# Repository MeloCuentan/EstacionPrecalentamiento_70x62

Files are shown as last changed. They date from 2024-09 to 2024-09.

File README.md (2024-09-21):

# Estacion de Precalentamiento

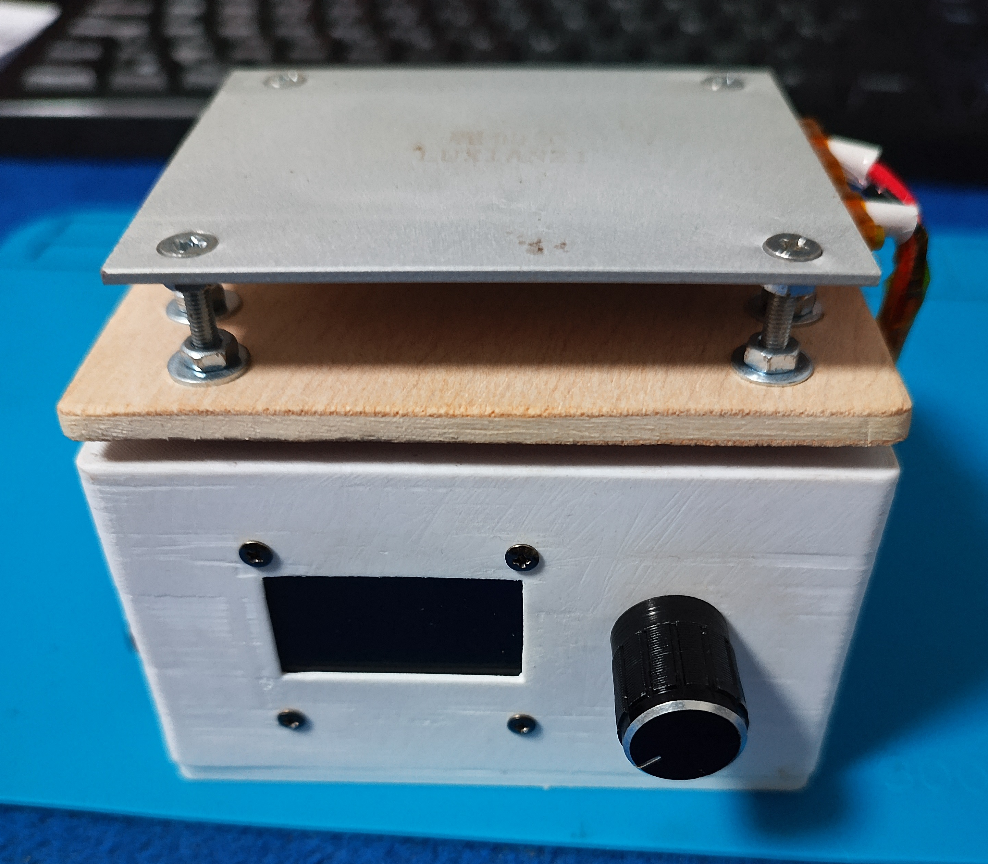
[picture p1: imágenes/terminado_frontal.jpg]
Foto Frontal


Esta es una estación de precalemtamiento para soldar componentes SMD en general
Está preparado para poder funcionar de 50 grados a 250 grados. 

Componentes utilizados:
- [LGT8F328P](https://es.aliexpress.com/item/1005006211738944.html)
- [HLK-5M05 5V 5W](https://es.aliexpress.com/item/1005003052023770.html)
- [SSR-D3805HK](https://es.aliexpress.com/item/1005004836016895.html)
- [Encoder EC11](https://es.aliexpress.com/item/1005003510208490.html)
- [NTC 100K 3950](https://es.aliexpress.com/item/1005007329695322.html)
- [OLED 1.3"](https://es.aliexpress.com/item/1005007038195466.html)
- [KF128-5.08-2P](https://es.aliexpress.com/item/1005006968553182.html)
- [Toma 220V](https://es.aliexpress.com/item/1005006361356458.html)
- [PTC 300W 62x70mm](https://es.aliexpress.com/item/1005001875752015.html)
- [47uF 16V](https://es.aliexpress.com/item/1005004883240789.html)
- [10nF y 100nF 0805](https://es.aliexpress.com/item/1005006054169207.html)
- [4K7 0805](https://es.aliexpress.com/item/1005002928942721.html)

Los tornillos que van puestos en la placa calentadora, se calientan bastante, así que la mejor solución ha sido poner un trozo de madera como placa intermedia.

El LGT8F328P se puede comprar el componente suelto. En mi caso tenía el del enlace y lo desoldé para ponerlo en la nueva

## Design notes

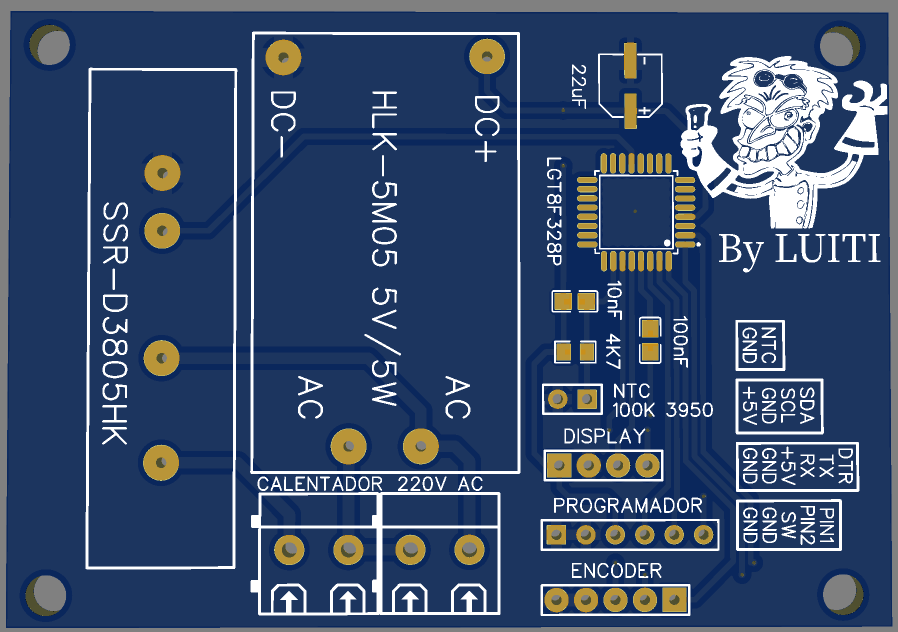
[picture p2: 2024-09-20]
VistaSuperiorPlaca.png

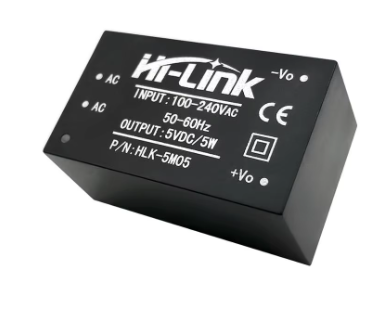
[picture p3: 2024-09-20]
imágenes/HLK-05M5_5V5W.png

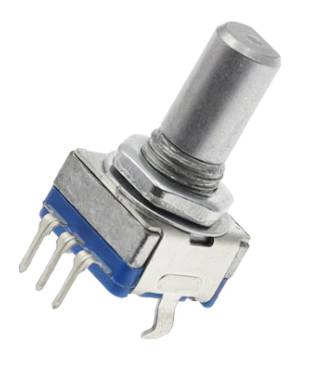
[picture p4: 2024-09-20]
imágenes/Encoder EC11.png

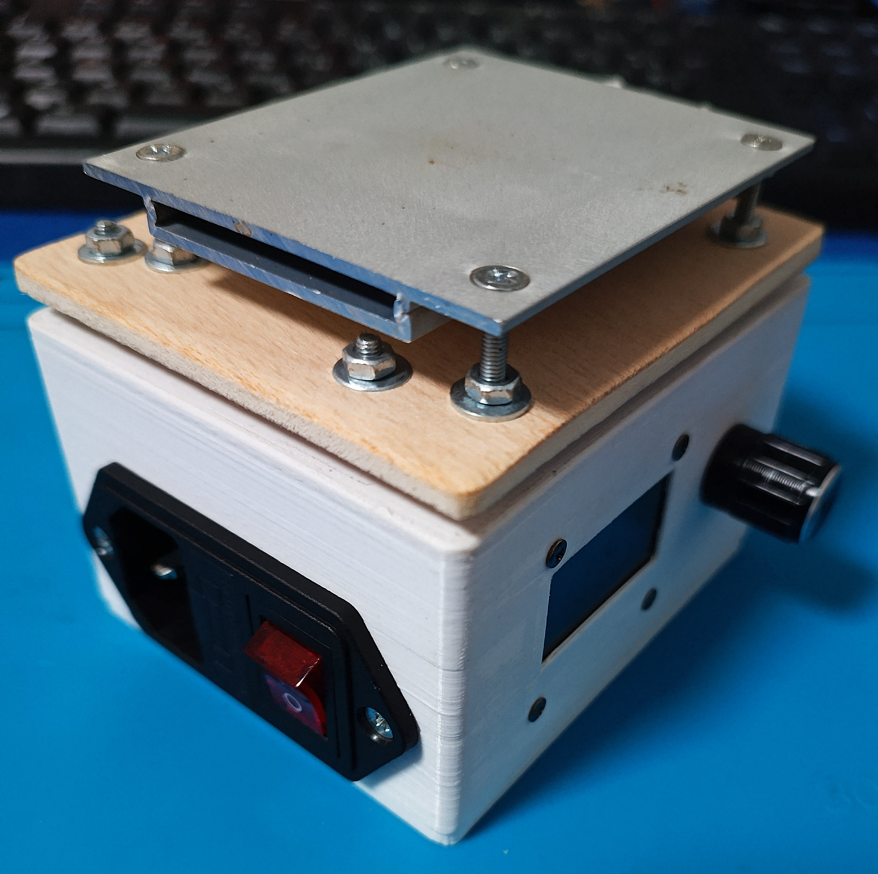
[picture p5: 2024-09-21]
imágenes/terminado_esquina.jpg

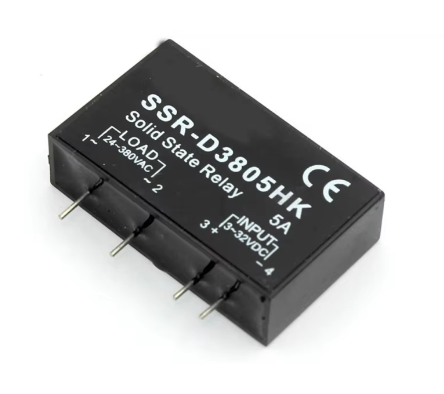
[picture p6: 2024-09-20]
imágenes/SSR-D3805HK.png

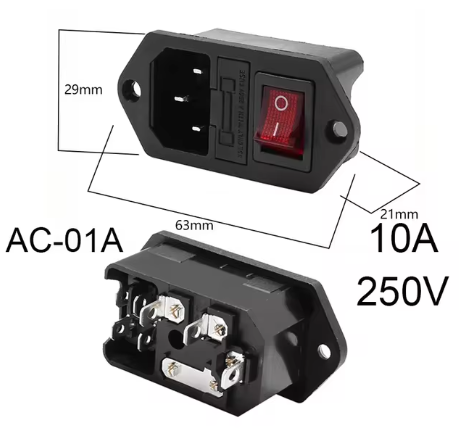
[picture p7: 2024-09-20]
imágenes/Enchufe220V.png

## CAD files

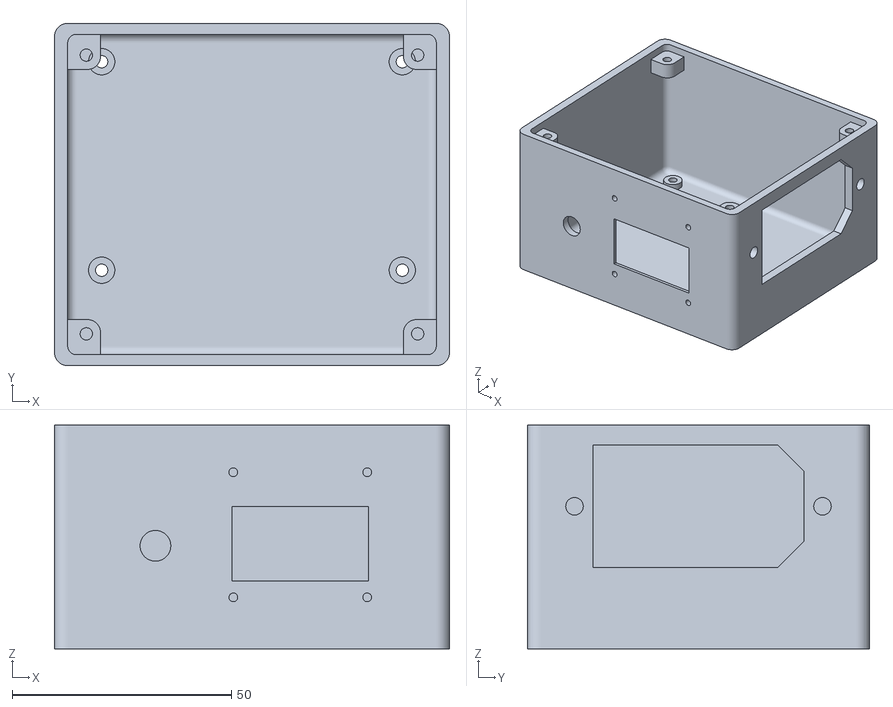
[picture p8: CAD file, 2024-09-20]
STL/Caja.stl
90.0 x 78.0 x 51.0

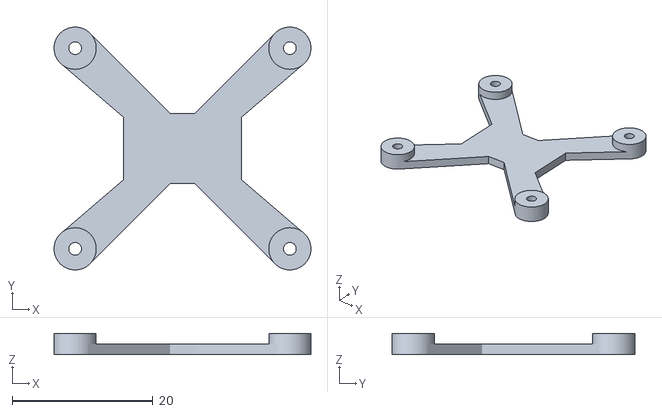
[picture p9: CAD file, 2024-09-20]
STL/Sujeción OLED.stl
36.5 x 34.5 x 3.00

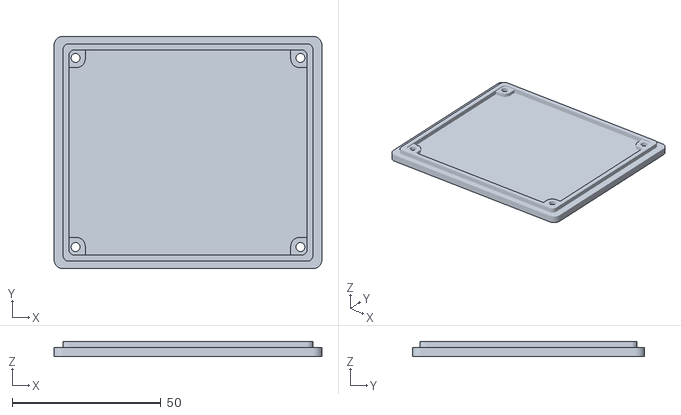
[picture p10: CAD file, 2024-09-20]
STL/Tapa.stl
90.0 x 78.0 x 5.00

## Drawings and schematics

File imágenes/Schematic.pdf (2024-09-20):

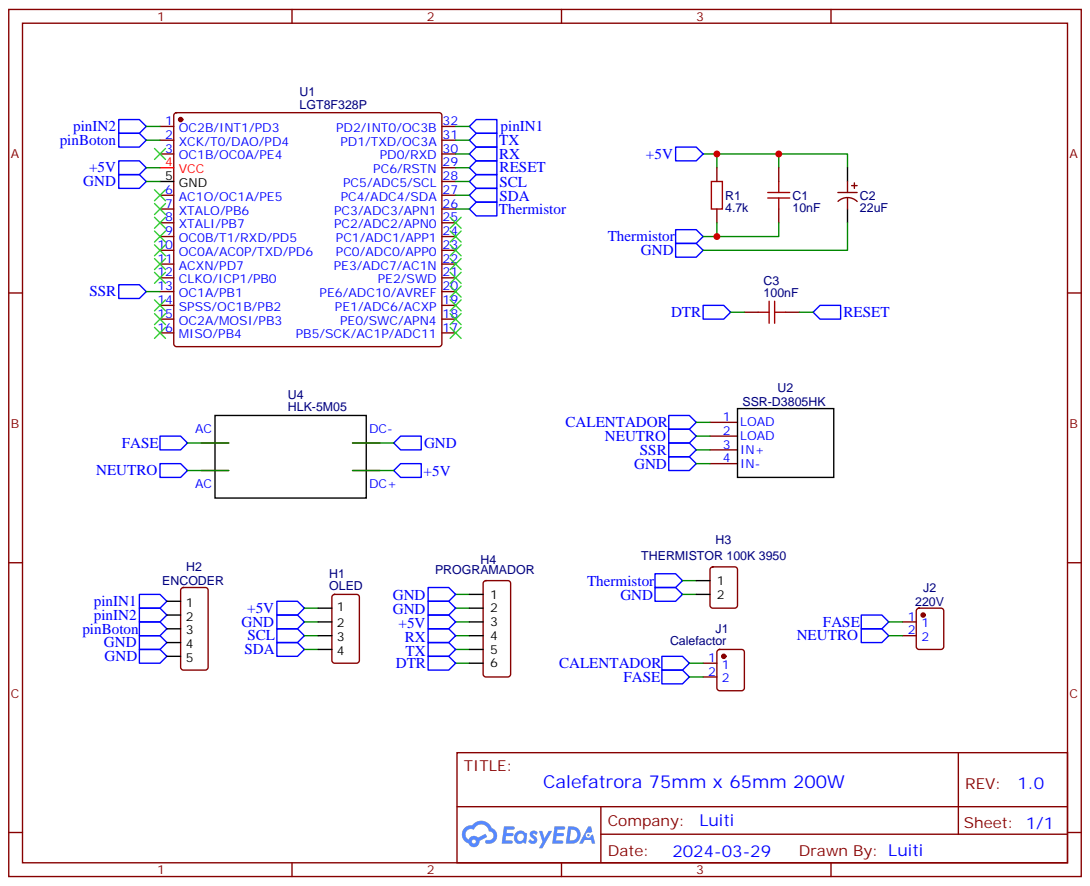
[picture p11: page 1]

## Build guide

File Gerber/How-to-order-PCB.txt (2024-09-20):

How to Order PCB

Please refer to:
https://docs.easyeda.com/en/PCB/Order-PCB

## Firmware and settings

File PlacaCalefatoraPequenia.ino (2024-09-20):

#include <Arduino.h>
#include <Wire.h>
#include <PID_v1.h>           // https://github.com/br3ttb/Arduino-PID-Library/tree/master
#include "sonda3950.h"        // https://github.com/MeloCuentan/termistor3950/
#include <RotaryEncoder.h>    // https://github.com/mathertel/RotaryEncoder
#include <Adafruit_SH110X.h>  // https://github.com/adafruit/Adafruit_SH110x/blob/master/Adafruit_SH110X.h
#include <Adafruit_GFX.h>     // https://github.com/adafruit/Adafruit-GFX-Library

// Valores de los pines utilizados
const uint8_t pinTermistor = A3;
const uint8_t pinSSR = 9;
const uint8_t pinEN1 = 3;
const uint8_t pinEN2 = 2;
const uint8_t pinBoton = 4;

// Valores del PID
double Setpoint = 0.0;
double Input = 0.0;
double Output = 0.0;

const double Kp = 1.35;
const double Ki = 0.02;
const double Kd = 2.0;

// Valores del display OLED
const uint8_t SCREEN_WIDTH = 128;
const uint8_t SCREEN_HEIGHT = 64;
const uint8_t SCREEN_ADDRESS = 0x3C;
const uint8_t TEXT_SIZE = 1;

// Valores generales de funcionamiento
const uint8_t temperaturaMinima = 50;
const uint16_t temperaturaMaxima = 250;
const uint16_t adcResolucion = 1023;
const uint16_t rPullUp = 4700;
const uint32_t rTermistor = 100000;
const float temperaturaInicio = 150.0;
uint32_t tiempoActual;

// Variables generales
bool estadoCalentador = false;
float valorSonda = 0;
uint16_t valorEncoder = 1;
uint16_t valorEncoderAnterior = 0;
bool lecturaBoton = false;

// Variables para generar PWM por software a baja frecuencia
const uint16_t frecuenciaPWM = 10;
const uint16_t duracionCiclo = 1000 / frecuenciaPWM;
uint16_t valorPWM = 0;

// Creamos objetos
sonda3950 termistor(pinTermistor, adcResolucion, rPullUp, rTermistor);
PID myPID(&Input, &Output, &Setpoint, Kp, Ki, Kd, DIRECT);
RotaryEncoder encoder(pinEN1, pinEN2, RotaryEncoder::LatchMode::FOUR3);
Adafruit_SH1106G display = Adafruit_SH1106G(SCREEN_WIDTH, SCREEN_HEIGHT);

// Declaramos funciones
void iniciarOLED();
void controlPWM(uint8_t duty);
void PID_Control();
void controlLimitesPID();
void pantallaInicio();
void medirTemperatura();
void comprobarEncoder();
String convertirNumeroAString(float numero, bool decimal);
void mostrarDisplay();

void setup() {
  pinMode(pinBoton, INPUT_PULLUP);
  pinMode(pinSSR, OUTPUT);
  Setpoint = temperaturaInicio;
  valorEncoder = Setpoint;

  analogReadResolution(10);

  encoder.setPosition(temperaturaInicio);
  myPID.SetMode(AUTOMATIC);

  termistor.begin();

  iniciarOLED();

  pantallaInicio();
}

void loop() {
  tiempoActual = millis();
  termistor.actualizar();
  comprobarEncoder();
  medirTemperatura();
  controlLimitesPID();
  PID_Control();
  mostrarDisplay();
}

void iniciarOLED() {
  display.begin(SCREEN_ADDRESS);
  display.clearDisplay();
  display.setRotation(0);
  display.setTextColor(SH110X_WHITE, SH110X_BLACK);
  display.setTextSize(TEXT_SIZE);
  display.setTextWrap(false);
  display.display();
}

void controlPWM(uint8_t duty) {
  static uint32_t tiempoAnterior;
  uint32_t onTime = (duracionCiclo * duty) / 255;
  uint32_t offTime = duracionCiclo - onTime;

  if (digitalRead(pinSSR) == HIGH && tiempoActual - tiempoAnterior >= onTime) {
    tiempoAnterior = tiempoActual;
    digitalWrite(pinSSR, LOW);
  } else if (digitalRead(pinSSR) == LOW && tiempoActual - tiempoAnterior >= offTime) {
    tiempoAnterior = tiempoActual;
    digitalWrite(pinSSR, HIGH);
  }
}

void PID_Control() {
  Input = valorSonda;
  myPID.Compute();

  if (estadoCalentador == true) {
    controlPWM(uint8_t(Output));
  } else {
    controlPWM(0);
    Output = 0;
  }
}

void controlLimitesPID() {
  int16_t diferencia = abs(int(Setpoint) - int(valorSonda));
  if (diferencia < 10) {
    myPID.SetOutputLimits(0, 15);
  } else if (diferencia < 50) {
    myPID.SetOutputLimits(0, 20);
  } else if (diferencia < 100) {
    myPID.SetOutputLimits(0, 30);
  } else {
    myPID.SetOutputLimits(0, 50);
  }
}

void pantallaInicio() {
  display.setCursor(13, 8);
  display.print("PLACA CALEFACTORA");
  display.setCursor(0, 24);
  display.print("POWER  -->");
  display.setCursor(0, 40);
  display.print("SET TEMP:");
  display.setCursor(0, 56);
  display.print("REAL TEMP:");
  display.drawCircle(96, 41, 2, SH110X_WHITE);
  display.drawCircle(108, 57, 2, SH110X_WHITE);
  display.setCursor(100, 40);
  display.print("C");
  display.setCursor(112, 56);
  display.print("C");
}

void medirTemperatura() {
  valorSonda = termistor.temperaturaLeida();
}

void comprobarEncoder() {
  static uint32_t tiempoDebounce, intervaloDebounce = 250;
  encoder.tick();

  valorEncoder = encoder.getPosition();
  if (valorEncoder < temperaturaMinima) {
    encoder.setPosition(temperaturaMinima);
    valorEncoder = temperaturaMinima;
  } else if (valorEncoder > temperaturaMaxima) {
    encoder.setPosition(temperaturaMaxima);
    valorEncoder = temperaturaMaxima;
  }

  if (valorEncoder != valorEncoderAnterior) {
    valorEncoderAnterior = valorEncoder;
    Setpoint = float(valorEncoder);
  }

  if (digitalRead(pinBoton) == LOW && lecturaBoton == true) {
    lecturaBoton = false;
    estadoCalentador = !estadoCalentador;
    tiempoDebounce = tiempoActual;
  }

  if (tiempoActual - tiempoDebounce >= intervaloDebounce && digitalRead(pinBoton) == HIGH) {
    lecturaBoton = true;
  }
}

String convertirNumeroAString(float numero, bool decimal) {
  String resultado = "";
  if (numero < 0) {
    resultado += "-";
    numero = -numero;
  } else {
    resultado += " ";
  }
  int parteEntera = (int)numero;
  if (parteEntera < 100) {
    resultado += " ";
  }
  resultado += String(parteEntera);
  if (decimal == true) {
    resultado += ".";
    int parteDecimal = (int)(numero * 10) % 10;
    resultado += String(parteDecimal);
  }
  return resultado;
}

void mostrarDisplay() {
  static uint32_t tiempoAnterior, intervalo = 250;

  if (tiempoActual - tiempoAnterior >= intervalo) {
    tiempoAnterior = tiempoActual;
    display.setCursor(72, 24);
    if (estadoCalentador)
      display.print("ON ");
    else
      display.print("OFF");

    display.setCursor(66, 40);
    display.print(convertirNumeroAString(Setpoint, false));

    display.setCursor(66, 56);
    display.print(convertirNumeroAString(valorSonda, true));

    display.display();
  }
}
